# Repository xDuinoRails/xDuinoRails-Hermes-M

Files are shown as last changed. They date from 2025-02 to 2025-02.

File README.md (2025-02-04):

# xDuinoRails-Hermes-M
Connect your DCC model railroad to a microcontroller:



## Description
Bridge your DCC model railroad to a microcontroller on a breadboard:

- Output: DCC signal for decoding (33k resistor)
- Input: DCC-ACK encoding to rails (60mA load)
- Input: RailCom encoding to rails (30mA current source)
- Power source (1): +5V 
- Power source (2): Recified railroad power

Built as breadboard friedly as possible.

## Buy your board

- https://www.tindie.com/products/chatelao/dccrailcom-interface-for-arduino-decoders/

## More pictures



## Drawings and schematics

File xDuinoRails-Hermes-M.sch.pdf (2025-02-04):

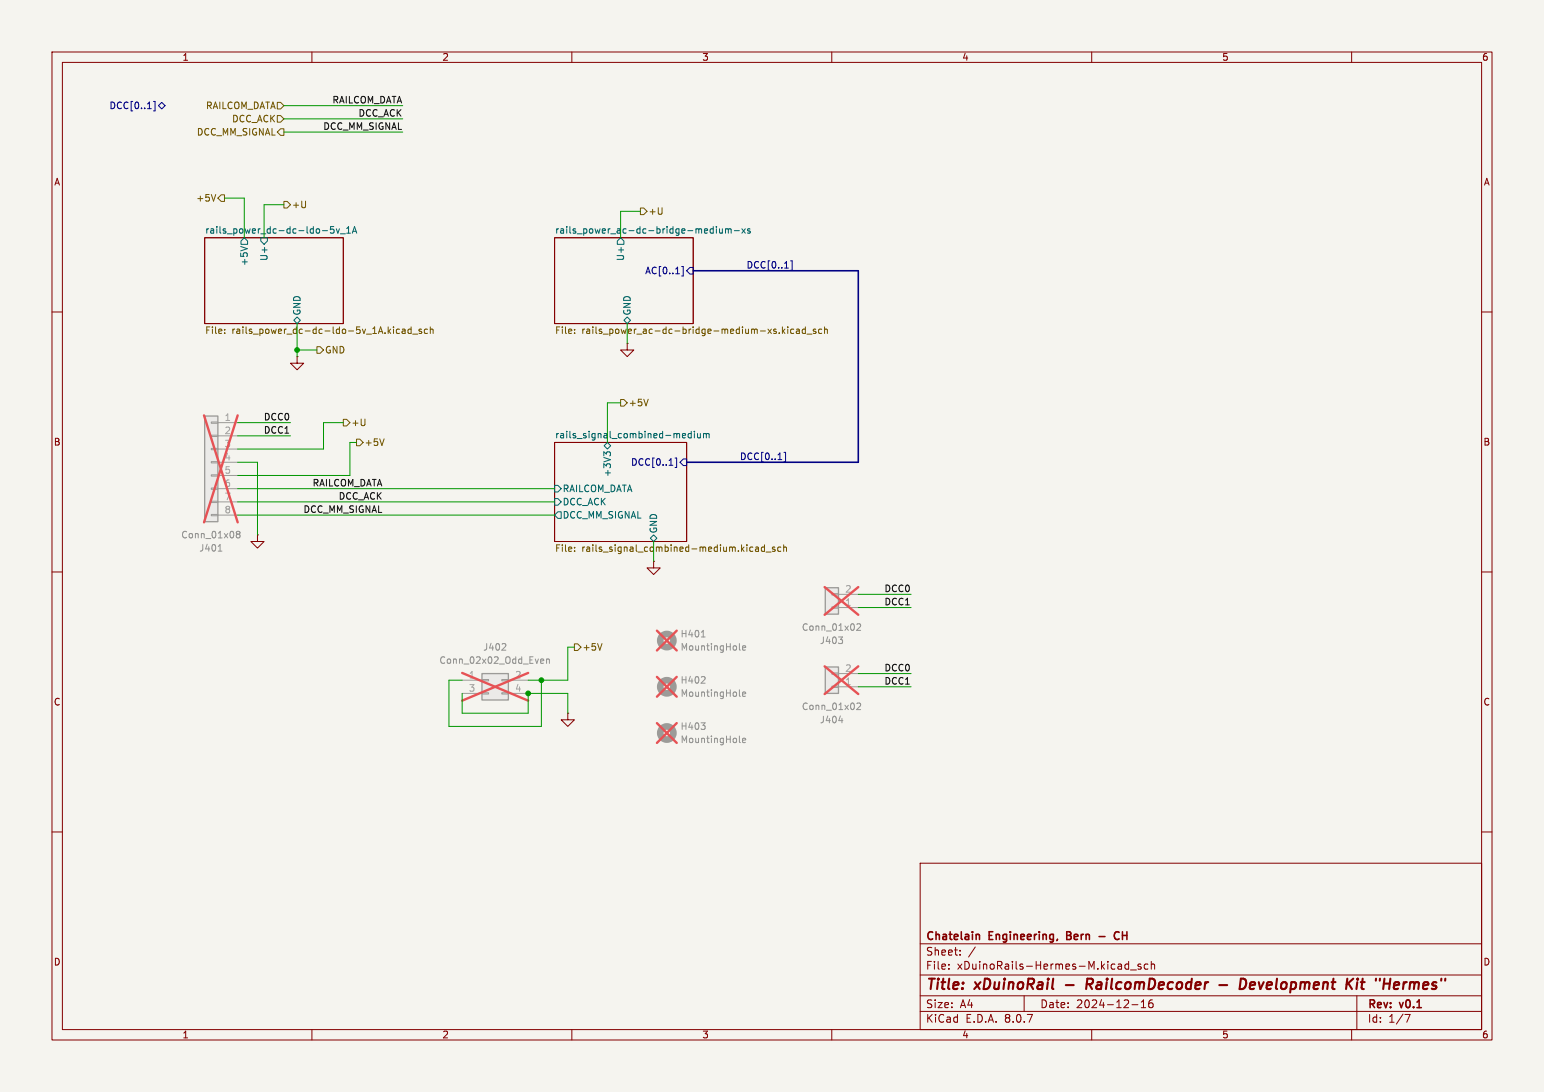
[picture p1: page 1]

rails_power_ac-dc-bridge-medium-xs File: rails_power_ac-dc-bridge-medium-xs.kicad_sch DCC_MM_SIGNAL GND

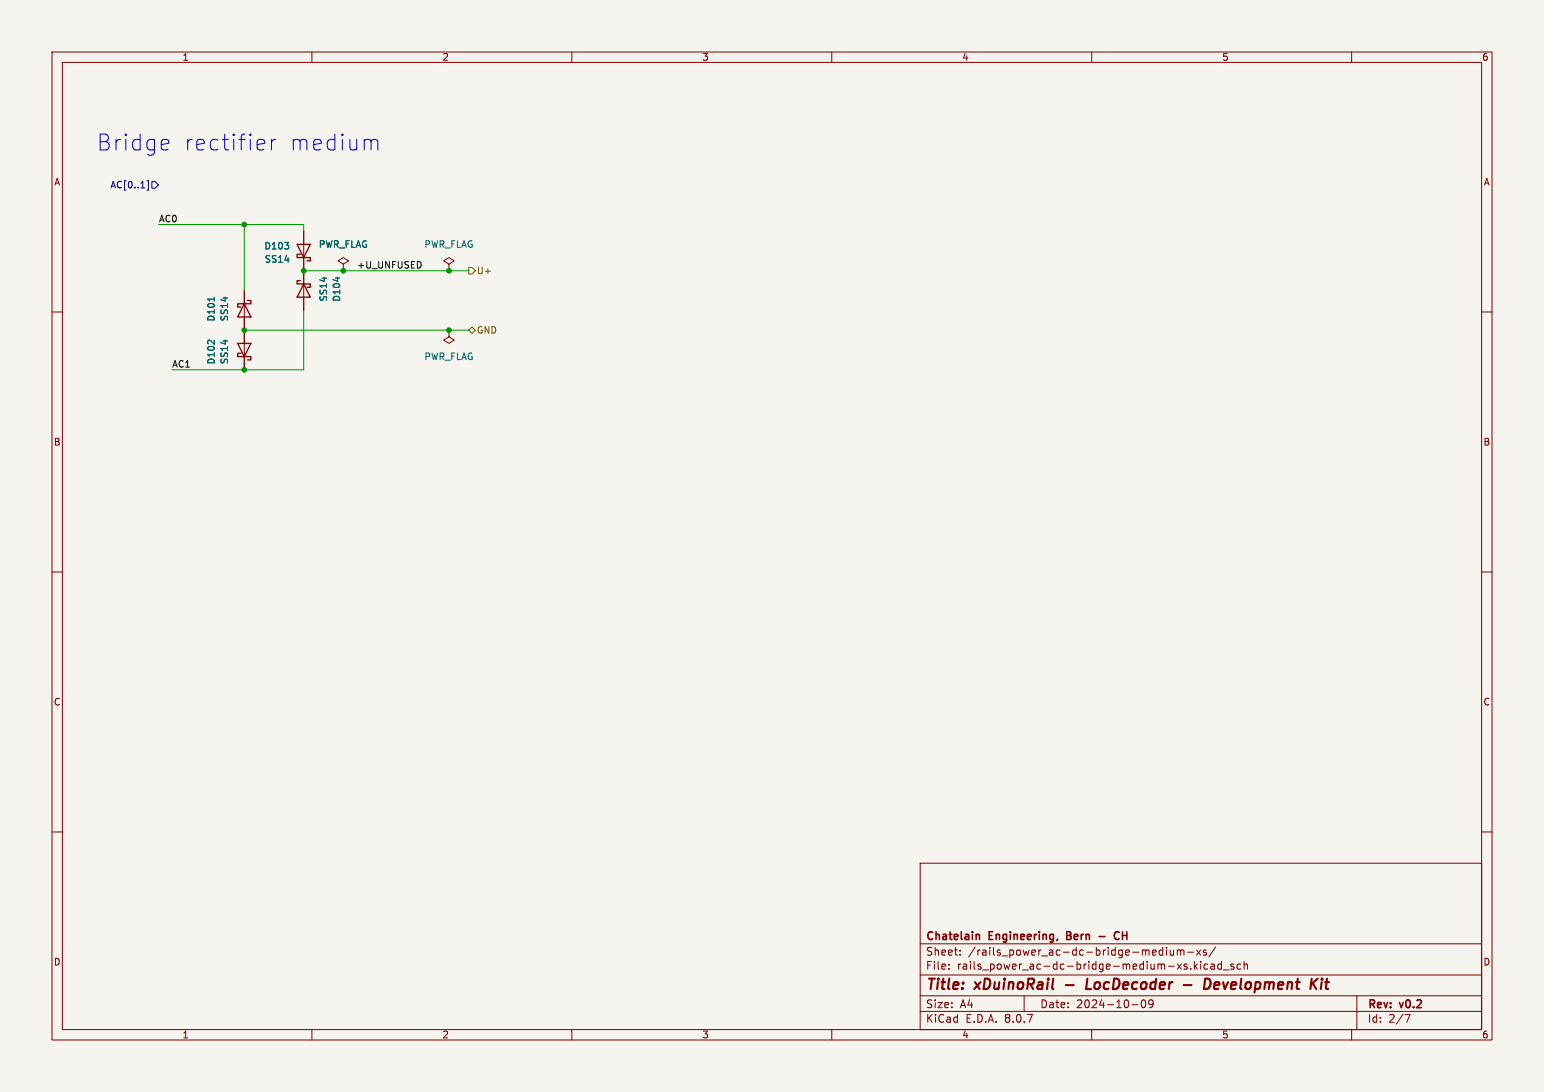
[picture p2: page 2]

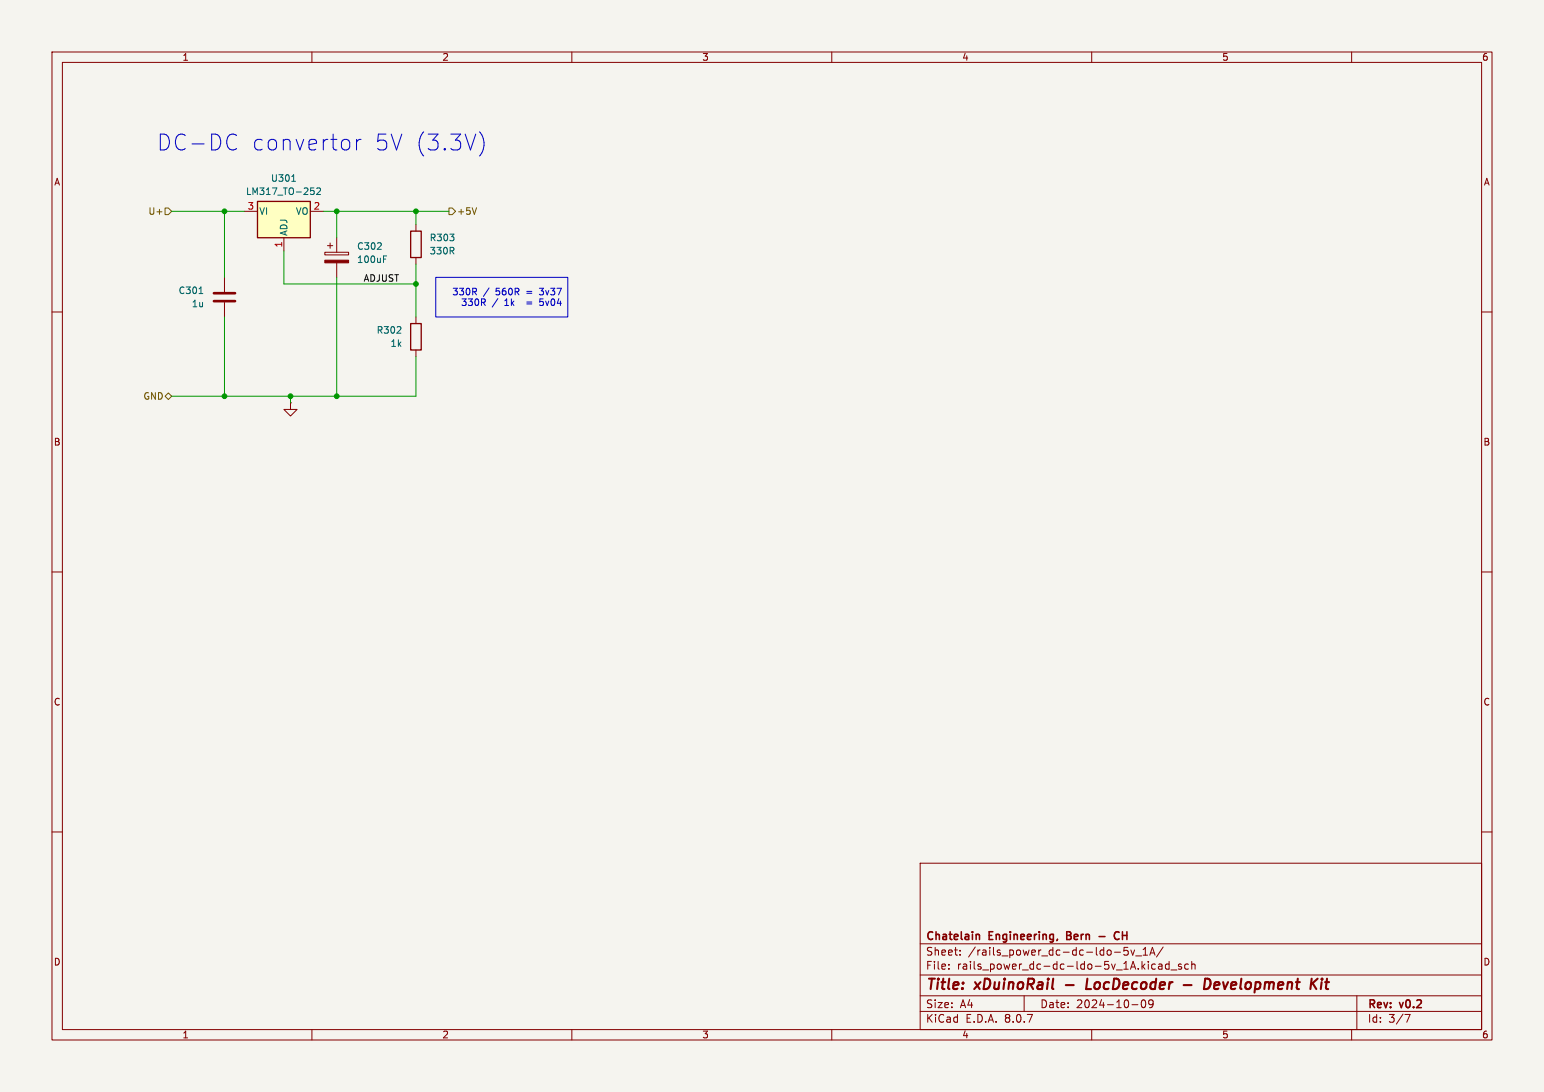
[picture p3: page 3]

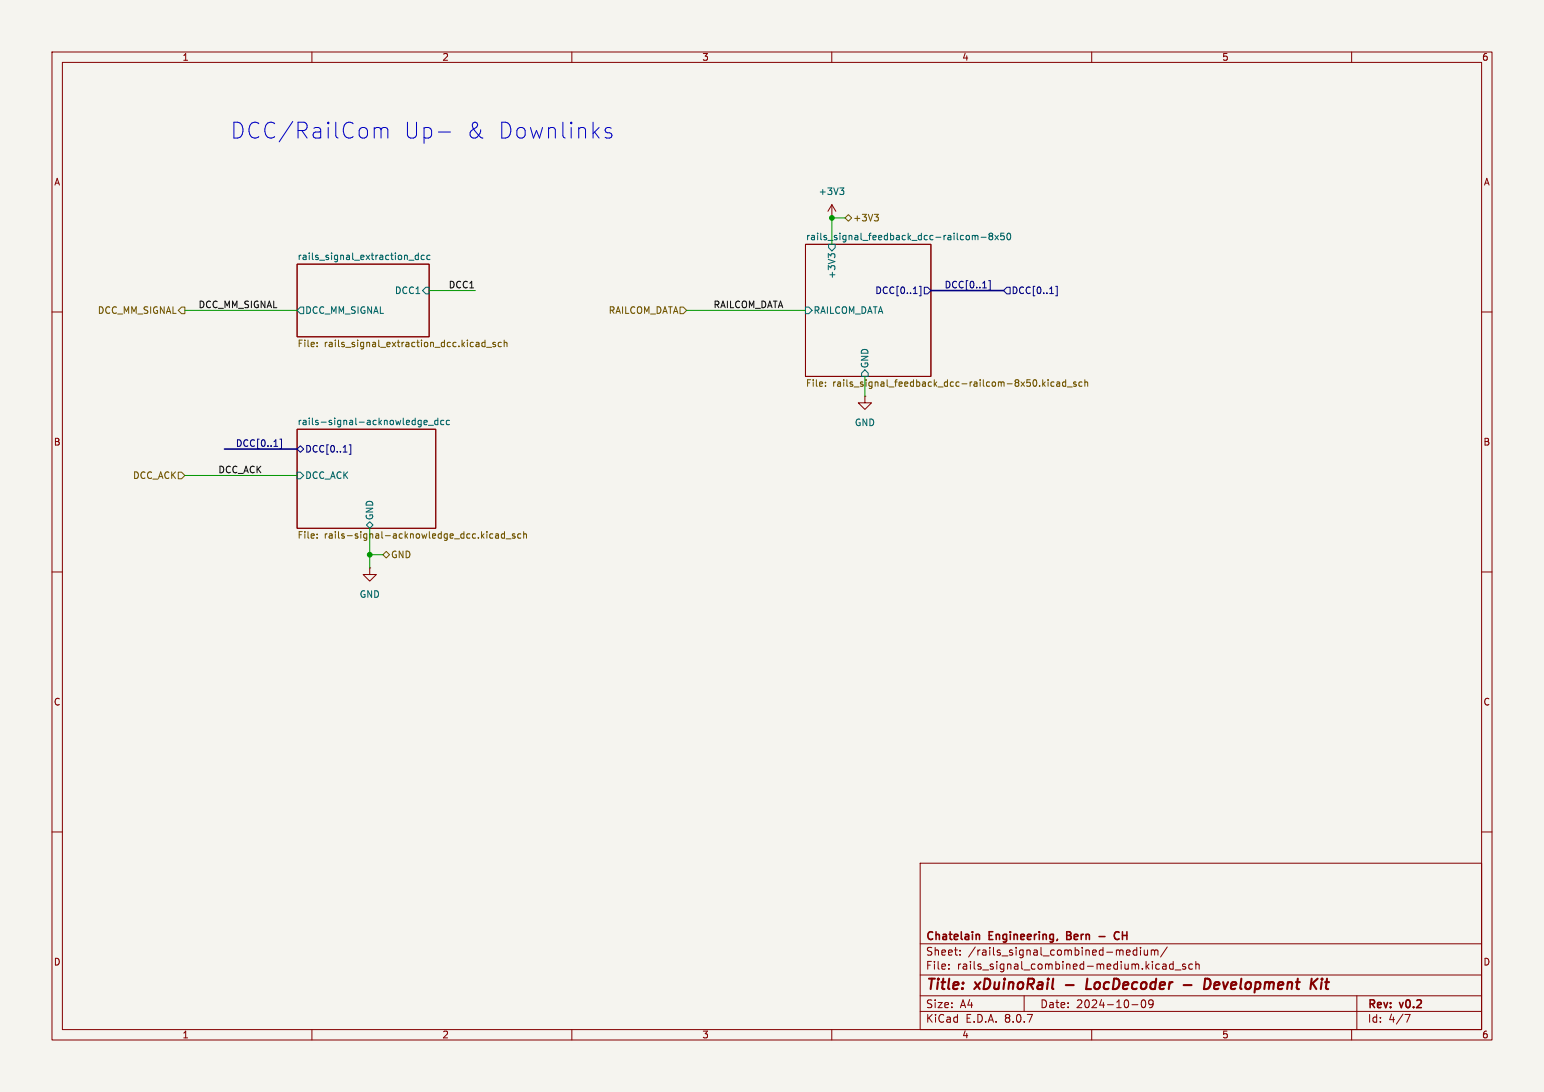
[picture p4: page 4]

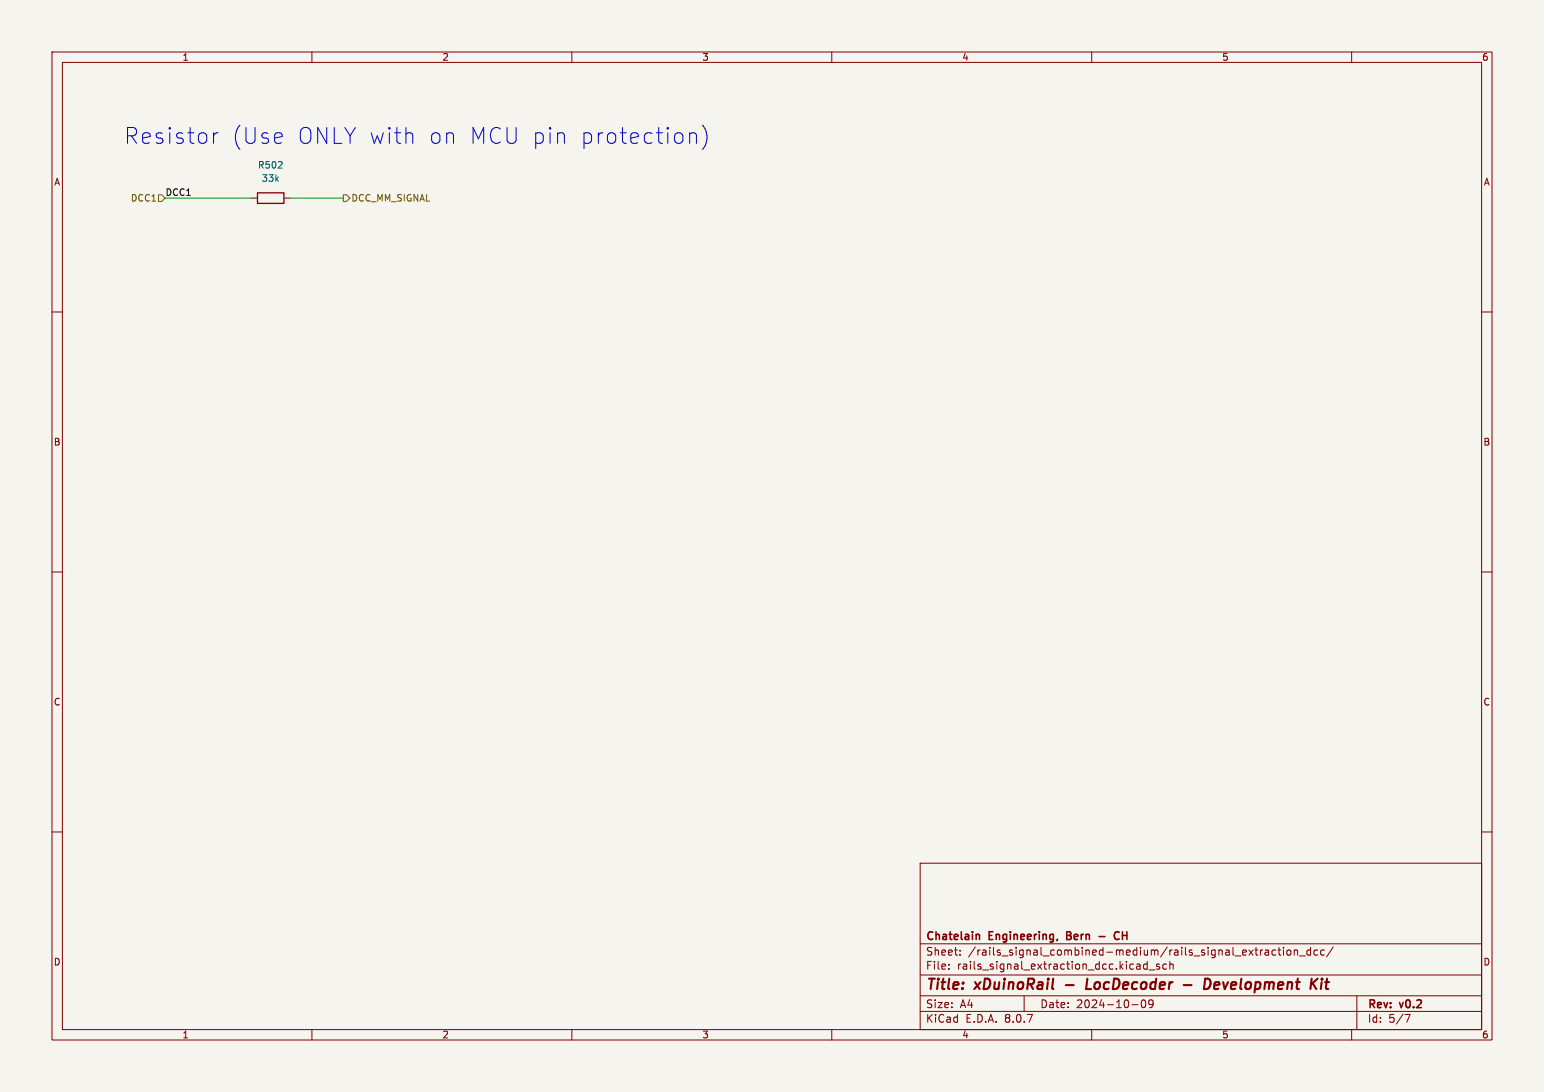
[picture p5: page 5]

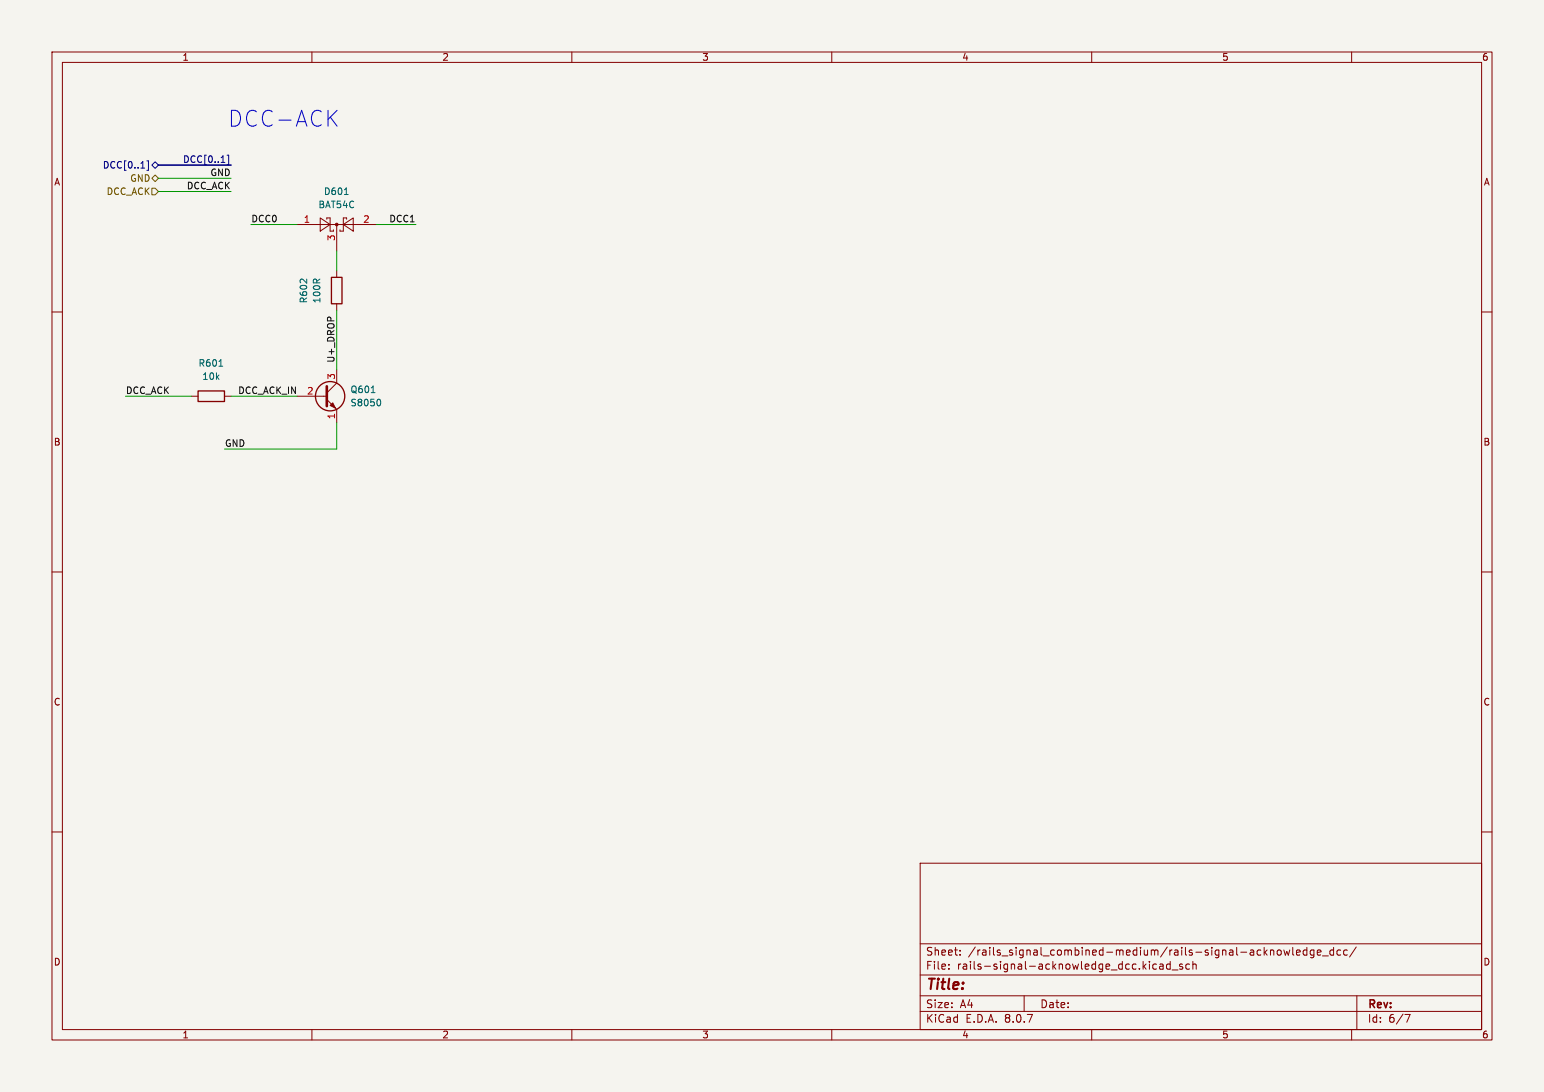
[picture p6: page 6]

Id: 6/7 Title: File: rails-signal-acknowledge_dcc.kicad_sch Sheet: /rails_signal_combined-medium/rails-signal-acknowledge_dcc/

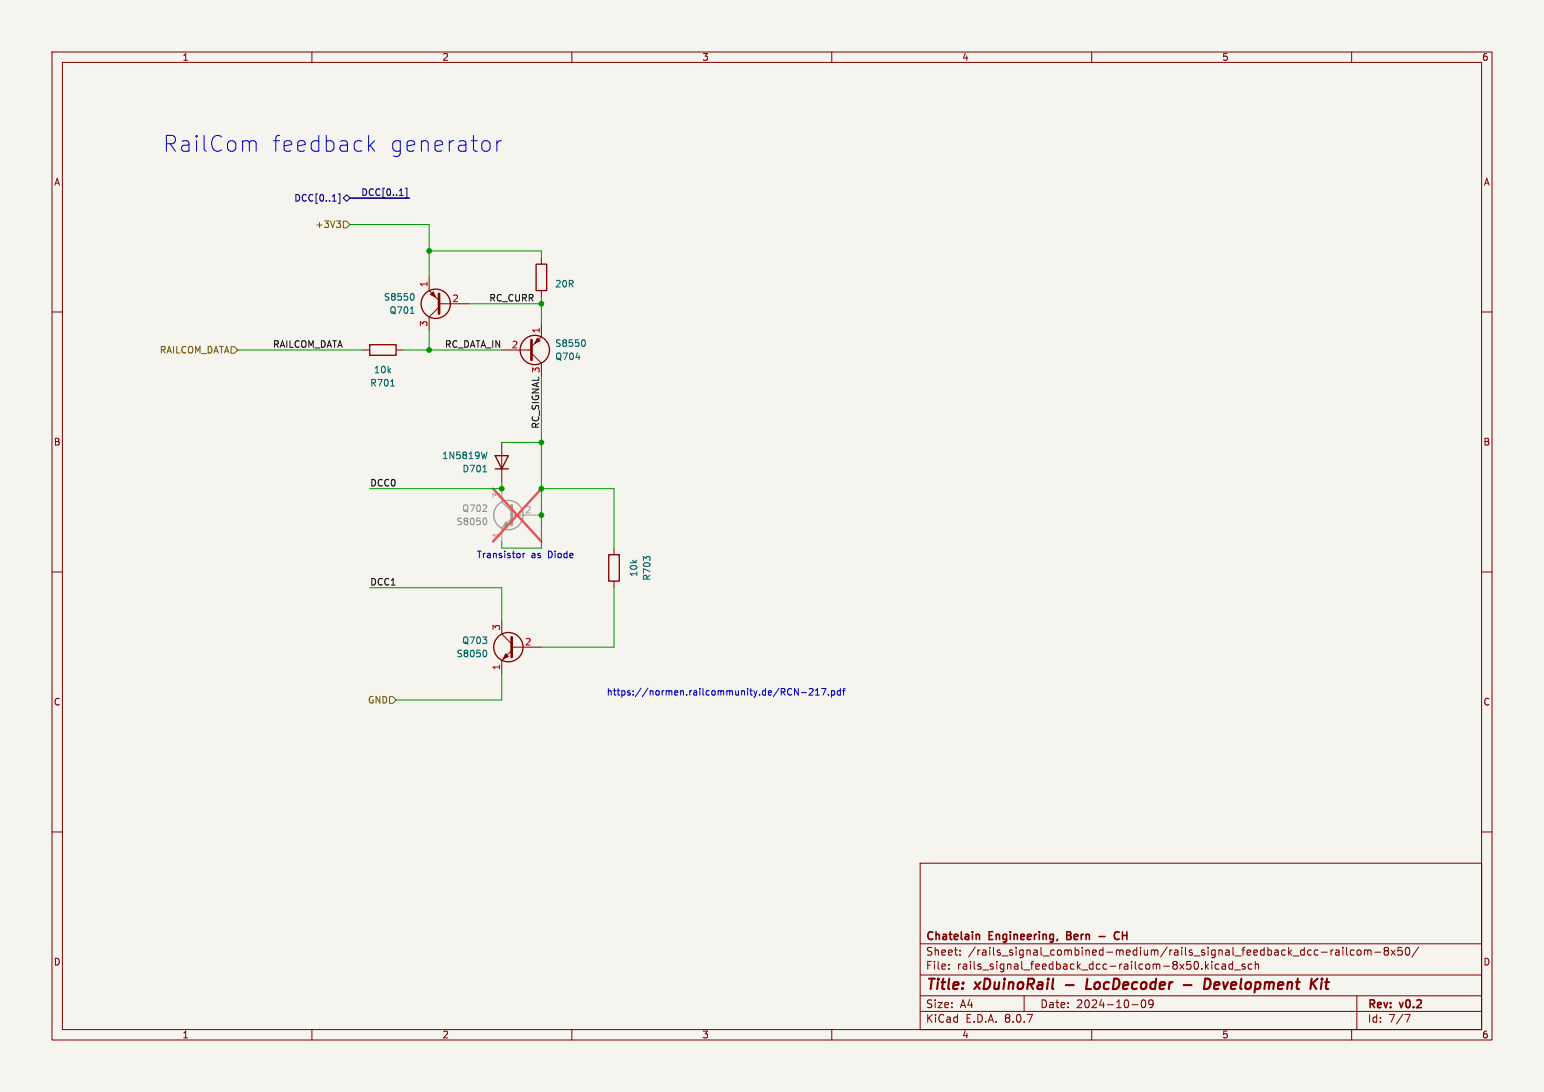
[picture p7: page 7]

https://normen.railcommunity.de/RCN-217.pdf

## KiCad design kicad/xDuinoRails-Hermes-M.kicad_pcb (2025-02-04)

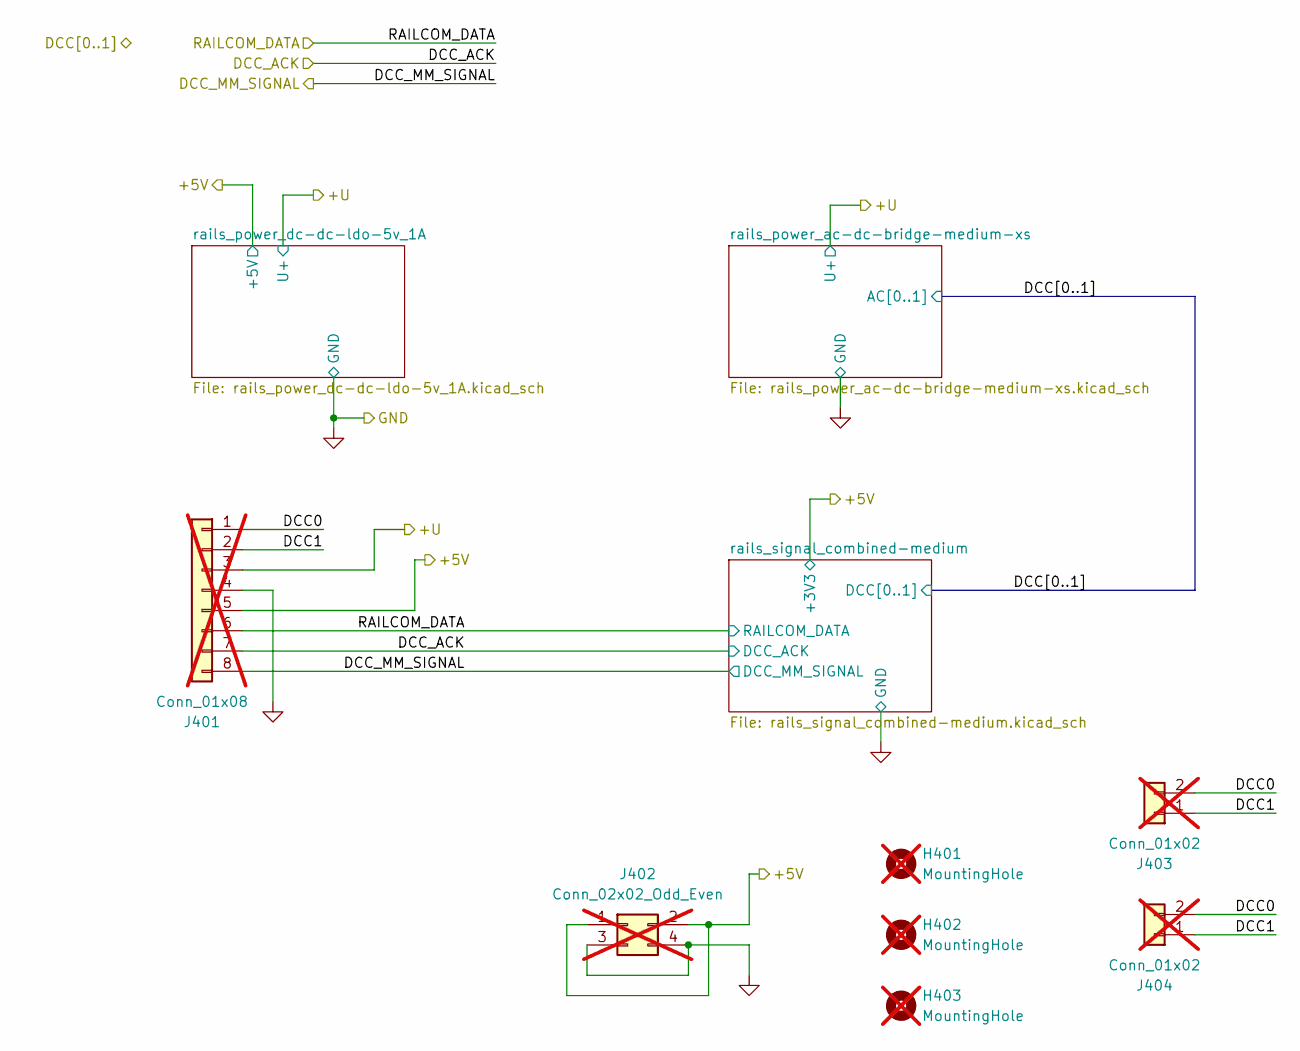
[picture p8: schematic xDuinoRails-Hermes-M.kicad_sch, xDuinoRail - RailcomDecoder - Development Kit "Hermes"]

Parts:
H401, H402, H403: MountingHole; MountingHole_3.2mm_M3; not fitted
J401: Conn_01x08; PinHeader_1x08_P2.54mm_Vertical; not fitted
J402: Conn_02x02_Odd_Even; PinHeader_2x02_P2.54mm_Vertical; not fitted
J403: Conn_01x02; PhoenixContact_MC_1,5_2-G-3.5_1x02_P3.50mm_Horizontal; not fitted
J404: Conn_01x02; SolderWire-1.5sqmm_1x02_P6mm_D1.7mm_OD3mm_Relief-Logo; not fitted

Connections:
+3V3: J401.5, J402.1, J402.2; also elsewhere on the board
/DCC0: J401.1, J403.2, J404.2; also elsewhere on the board
/DCC1: J401.2, J403.1, J404.1; also elsewhere on the board
/DCC_ACK: J401.7; also elsewhere on the board
/DCC_MM_SIGNAL: J401.8; also elsewhere on the board
/RAILCOM_DATA: J401.6; also elsewhere on the board
/rails_power_ac-dc-bridge-medium-xs/+U_UNFUSED: J401.3; also elsewhere on the board
GND: J401.4, J402.3, J402.4; also elsewhere on the board

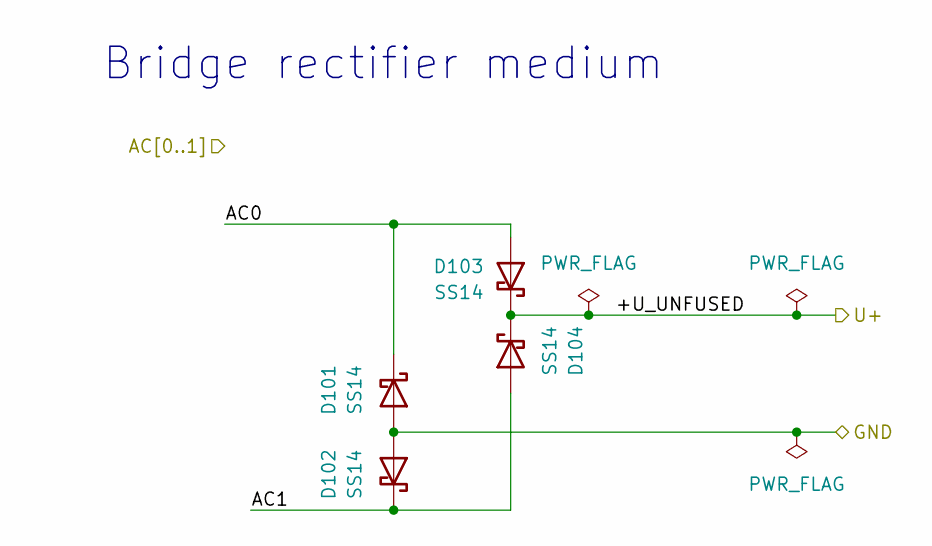
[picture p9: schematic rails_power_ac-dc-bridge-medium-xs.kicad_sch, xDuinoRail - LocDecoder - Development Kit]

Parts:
D101, D102, D103, D104: SS14; D_SMA

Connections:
/DCC0: D101.1 (K), D103.2 (A); also elsewhere on the board
/DCC1: D102.1 (K), D104.2 (A); also elsewhere on the board
/rails_power_ac-dc-bridge-medium-xs/+U_UNFUSED: D103.1 (K), D104.1 (K); also elsewhere on the board
GND: D101.2 (A), D102.2 (A); also elsewhere on the board

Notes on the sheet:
Bridge rectifier medium

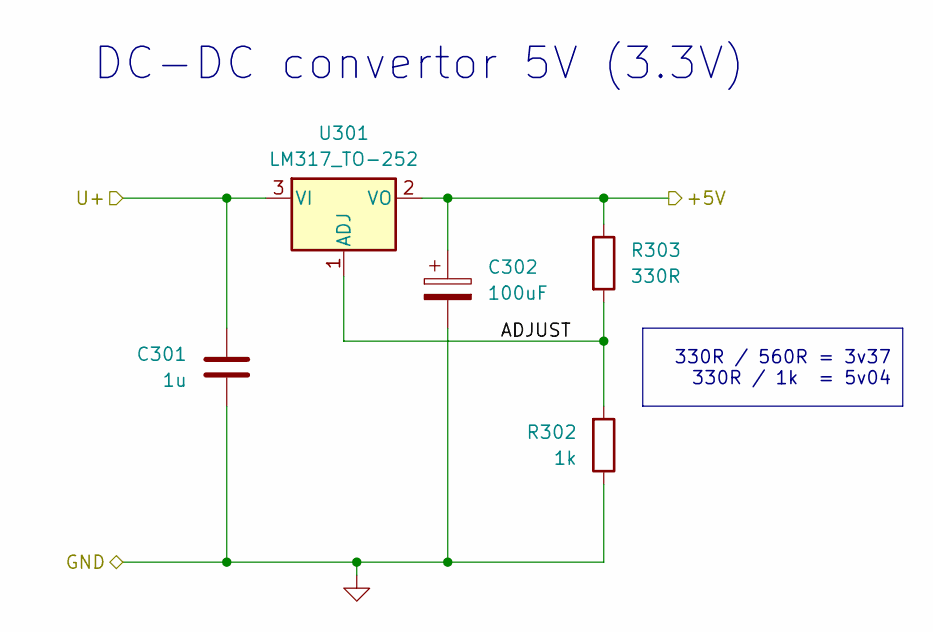
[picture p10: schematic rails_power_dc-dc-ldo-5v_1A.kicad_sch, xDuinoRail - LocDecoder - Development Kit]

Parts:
C301: 1u; C_0603_1608Metric_Pad1.08x0.95mm_HandSolder
C302: 100uF; C_1206_3216Metric_Pad1.33x1.80mm_HandSolder
R302: 1k; R_0805_2012Metric_Pad1.20x1.40mm_HandSolder
R303: 330R; R_0805_2012Metric_Pad1.20x1.40mm_HandSolder
U301: LM317_TO-252; TO-252-2

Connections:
+3V3: C302.1, R303.1, U301.2 (VO); also elsewhere on the board
/rails_power_ac-dc-bridge-medium-xs/+U_UNFUSED: C301.1, U301.3 (VI); also elsewhere on the board
/rails_power_dc-dc-ldo-5v_1A/ADJUST: R302.2, R303.2, U301.1 (ADJ)
GND: C301.2, C302.2, R302.1; also elsewhere on the board

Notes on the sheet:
330R / 560R = 3v37 330R / 1k = 5v04
DC-DC convertor 5V (3.3V)

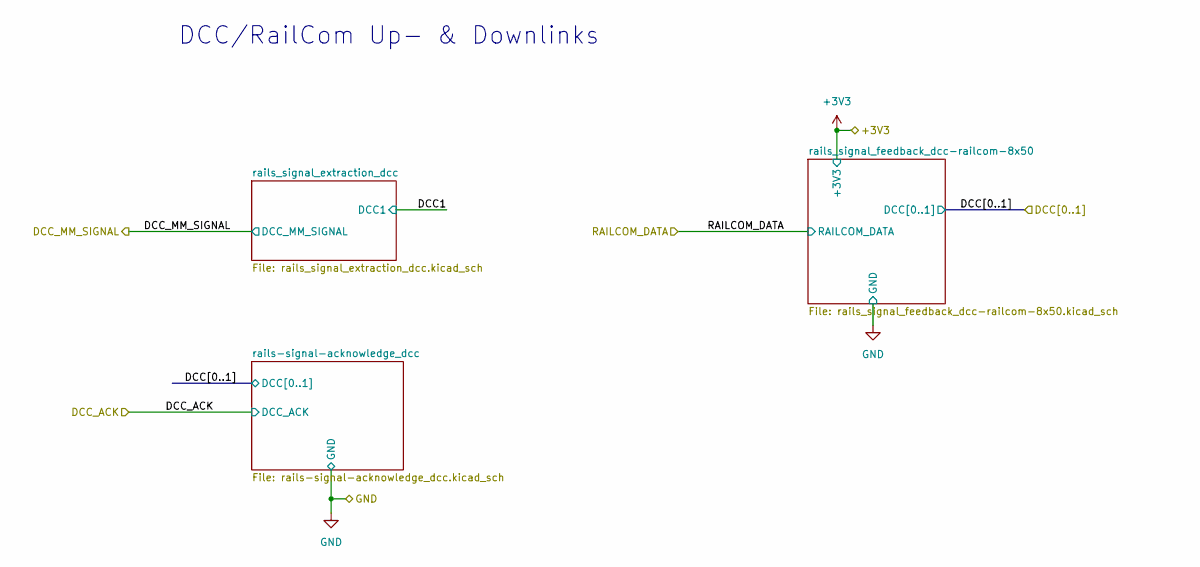
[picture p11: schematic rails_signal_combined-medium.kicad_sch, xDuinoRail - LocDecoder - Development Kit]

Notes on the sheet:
DCC/RailCom Up- & Downlinks

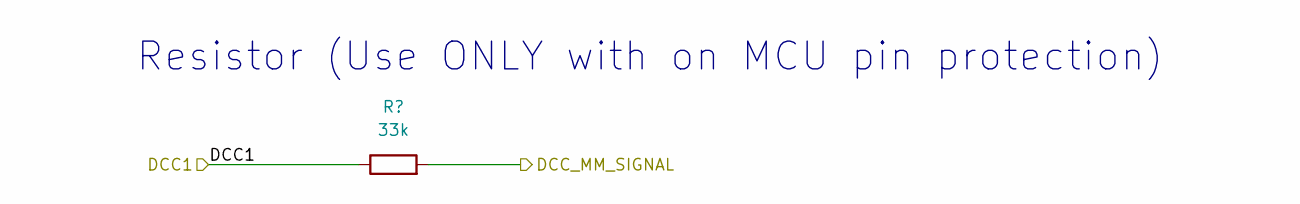
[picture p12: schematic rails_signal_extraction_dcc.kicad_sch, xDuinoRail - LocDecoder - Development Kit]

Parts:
R502: 33k; R_0805_2012Metric_Pad1.20x1.40mm_HandSolder

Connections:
/DCC1: R502.1; also elsewhere on the board
/DCC_MM_SIGNAL: R502.2; also elsewhere on the board

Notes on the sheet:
Resistor (Use ONLY with on MCU pin protection)

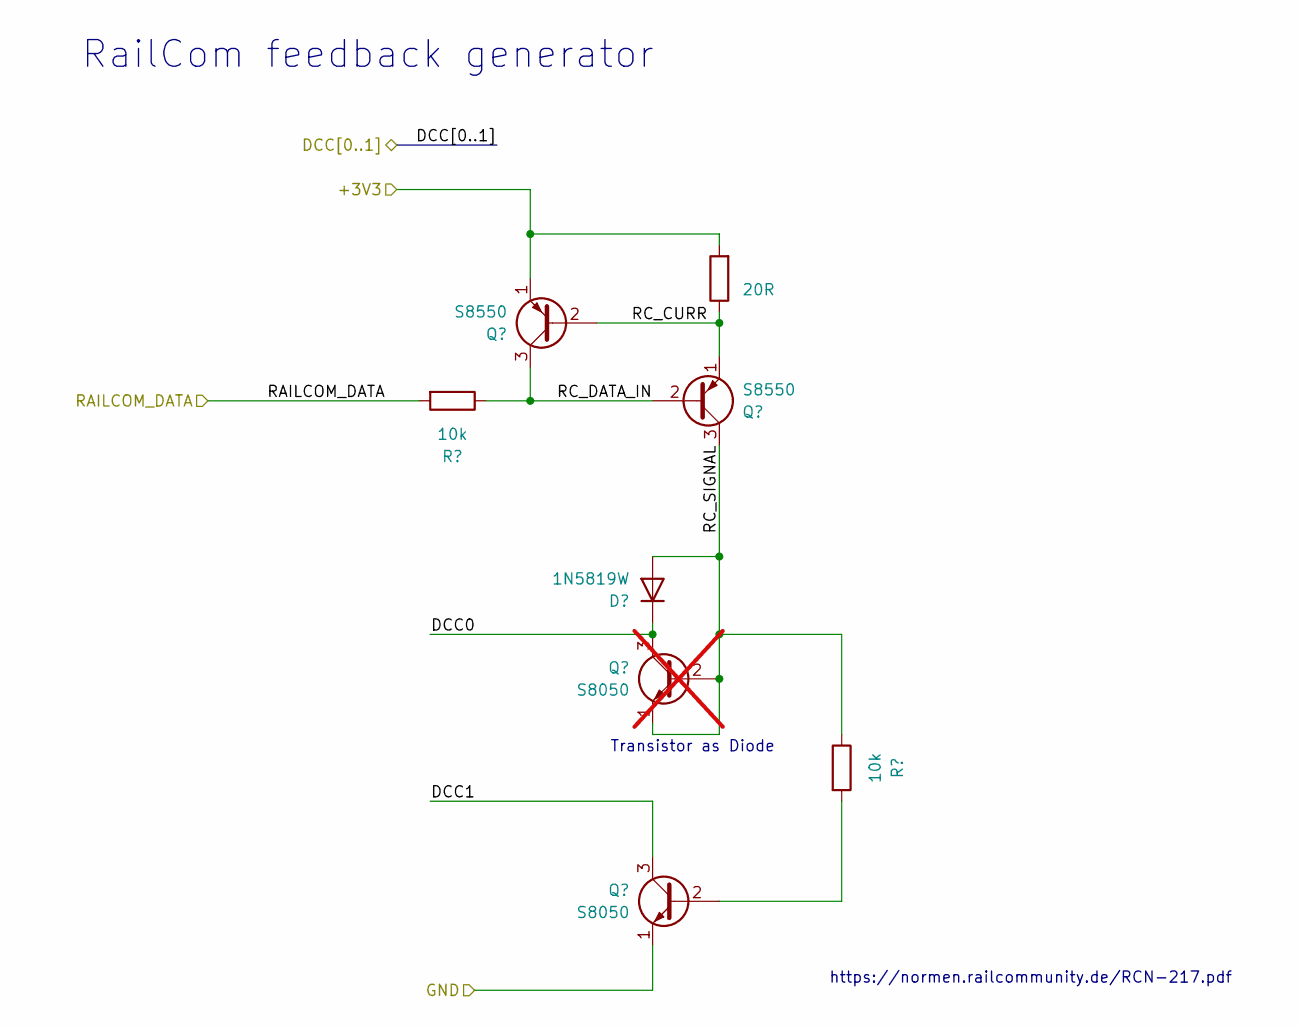
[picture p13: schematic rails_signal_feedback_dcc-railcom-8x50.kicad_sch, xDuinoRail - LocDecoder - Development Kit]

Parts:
D701: 1N5819W; D_SOD-123; LCSC C81598
Q701, Q704: S8550; 8x50_SOT-23; LCSC C8542
Q702: S8050; 8x50_SOT-23; LCSC C2150; not fitted
Q703: S8050; 8x50_SOT-23; LCSC C2150
R701, R703: 10k; R_0603_1608Metric_Pad0.98x0.95mm_HandSolder; LCSC C25744
R702: 20R; R_0603_1608Metric_Pad0.98x0.95mm_HandSolder; LCSC C22950

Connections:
+3V3: Q701.1 (E), R702.2; also elsewhere on the board
/DCC0: D701.1 (K), Q702.3 (C); also elsewhere on the board
/DCC1: Q703.3 (C); also elsewhere on the board
/RAILCOM_DATA: R701.2; also elsewhere on the board
/rails_signal_combined-medium/rails_signal_feedback_dcc-railcom-8x50/RC_CURR: Q701.2 (B), Q704.1 (E), R702.1
/rails_signal_combined-medium/rails_signal_feedback_dcc-railcom-8x50/RC_DATA_IN: Q701.3 (C), Q704.2 (B), R701.1
/rails_signal_combined-medium/rails_signal_feedback_dcc-railcom-8x50/RC_SIGNAL: D701.2 (A), Q702.1 (E), Q702.2 (B), Q704.3 (C), R703.1
GND: Q703.1 (E); also elsewhere on the board
unnamed: Q703.2 (B), R703.2

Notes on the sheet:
Transistor as Diode
RailCom feedback generator
https://normen.railcommunity.de/RCN-217.pdf

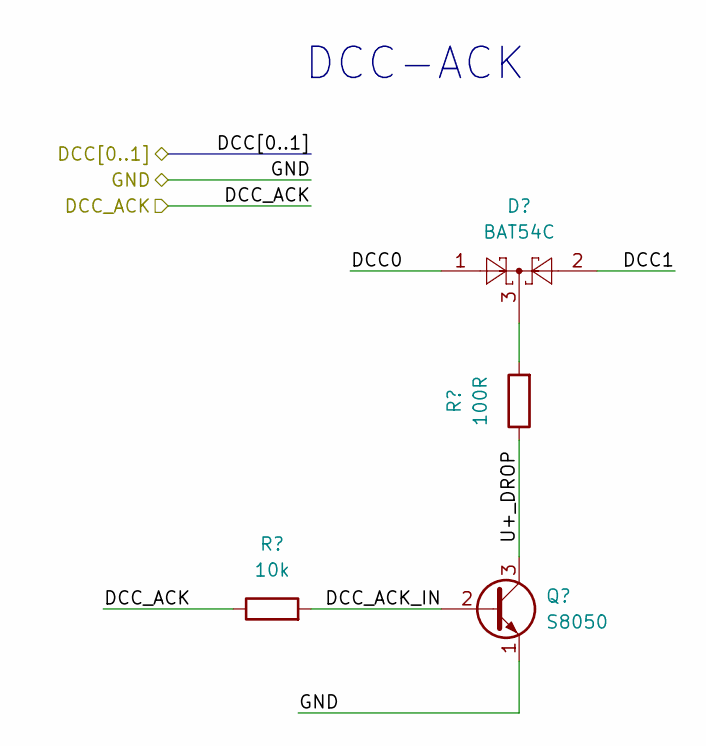
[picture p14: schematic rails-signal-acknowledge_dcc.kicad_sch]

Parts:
D601: BAT54C; 8x50_SOT-23
Q601: S8050; 8x50_SOT-23; LCSC C2150
R601: 10k; R_0603_1608Metric_Pad0.98x0.95mm_HandSolder; LCSC C25744
R602: 100R; R_0603_1608Metric_Pad0.98x0.95mm_HandSolder; LCSC C25744

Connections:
/DCC0: D601.1; also elsewhere on the board
/DCC1: D601.2; also elsewhere on the board
/DCC_ACK: R601.1; also elsewhere on the board
/rails_signal_combined-medium/rails-signal-acknowledge_dcc/DCC_ACK_IN: Q601.2 (B), R601.2
/rails_signal_combined-medium/rails-signal-acknowledge_dcc/U+_DROP: Q601.3 (C), R602.1
GND: Q601.1 (E); also elsewhere on the board
unnamed: D601.3, R602.2

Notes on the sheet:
DCC-ACK

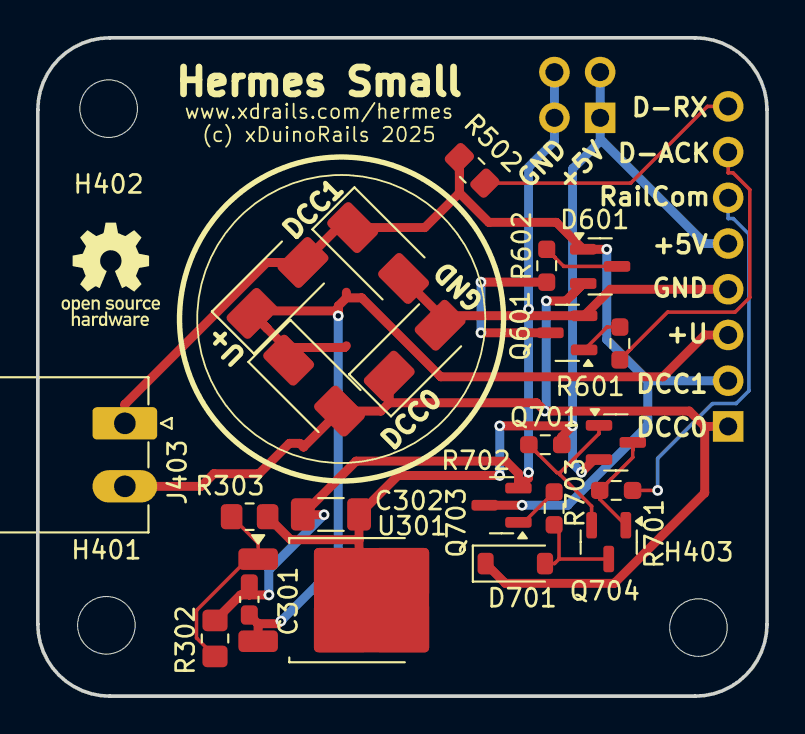
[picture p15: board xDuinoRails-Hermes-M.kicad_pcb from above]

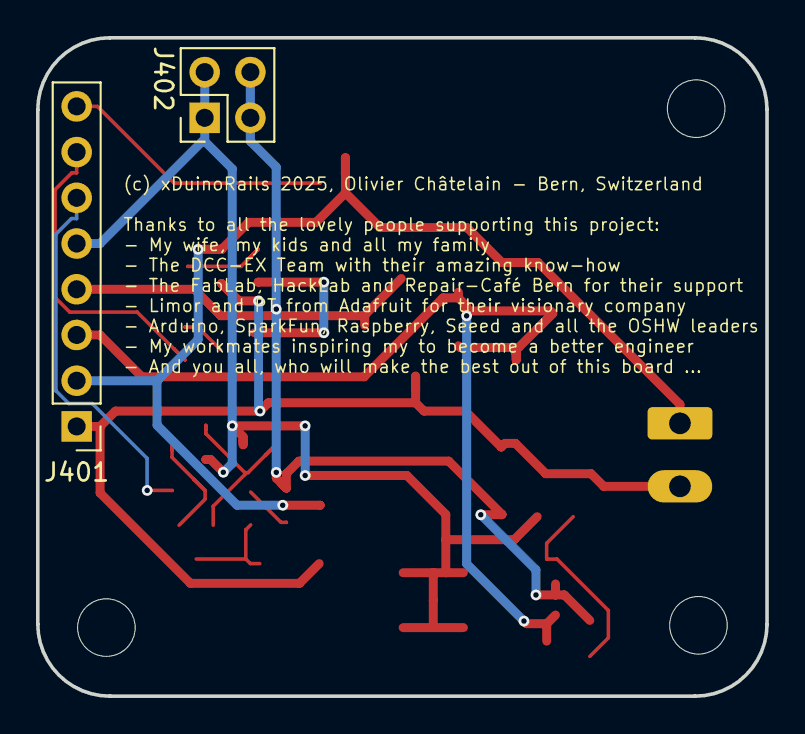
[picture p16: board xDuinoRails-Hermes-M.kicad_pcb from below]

Board: 2 copper layers, 40.5 x 36.6 mm, 27 parts (2 on the bottom side), 16 nets.
